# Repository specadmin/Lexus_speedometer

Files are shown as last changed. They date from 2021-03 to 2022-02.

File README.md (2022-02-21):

# Модуль перевода показаний спидометра Lexus RX300 в километры в час #

Владельцы Lexus RX300 американского производства знают, что спидометр данного авто имеет две шкалы - крупную в милях в час и мелкую - в км/ч. В связи с этим считывание показаний спидометра в нужных нам единицах несколько затруднено. Предлагаемое устройство призвано решить эту проблему путем "переноса" действительных показаний спидометра в км/ч с мелкой шкалы на крупную.

Устройство подходит для приборных панелей Lexus RX300 1-го поколения (1998...2003).

Результат выглядит так:
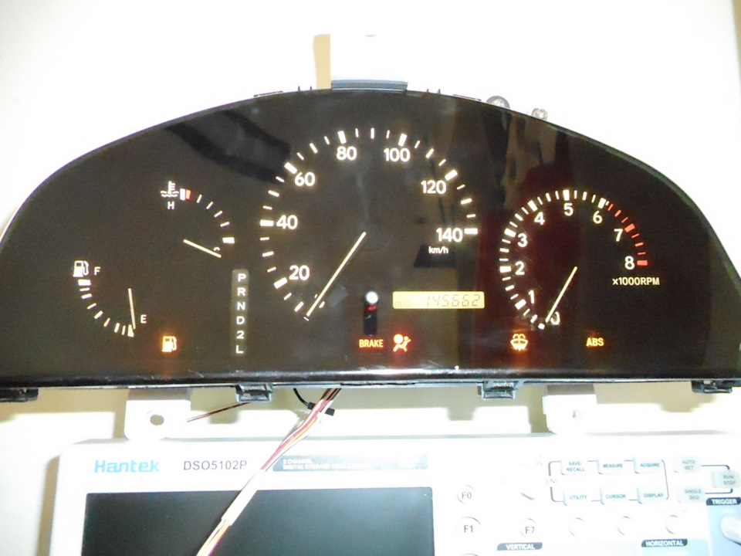
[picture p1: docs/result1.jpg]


Элементы мелкой шкалы и MPH заклеиваются черной изолентой:
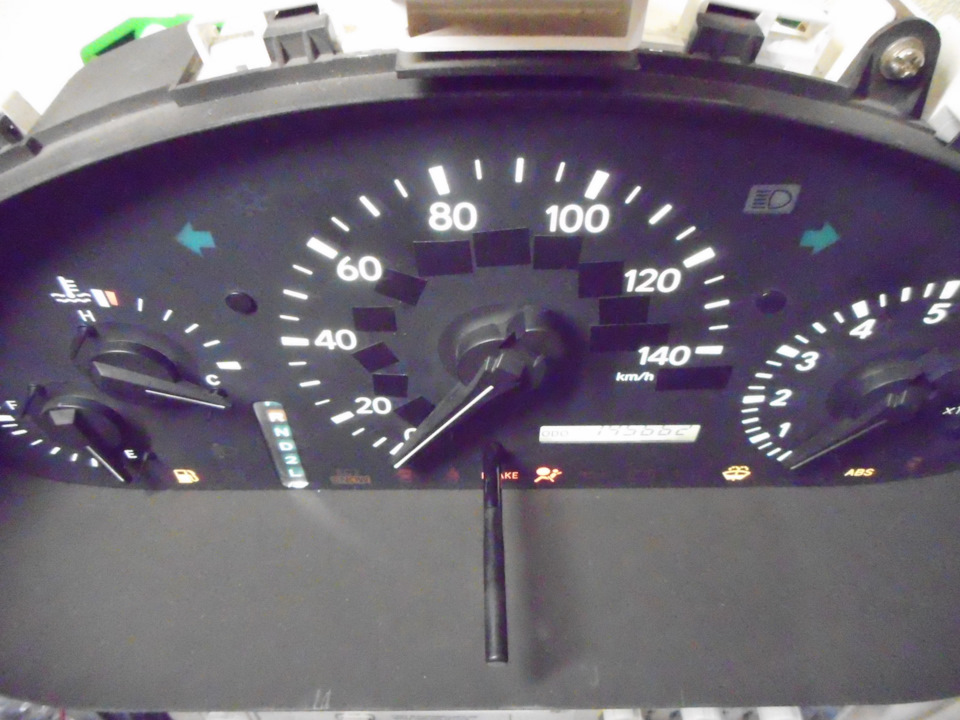
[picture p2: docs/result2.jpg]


Принципиальная схема устройства:
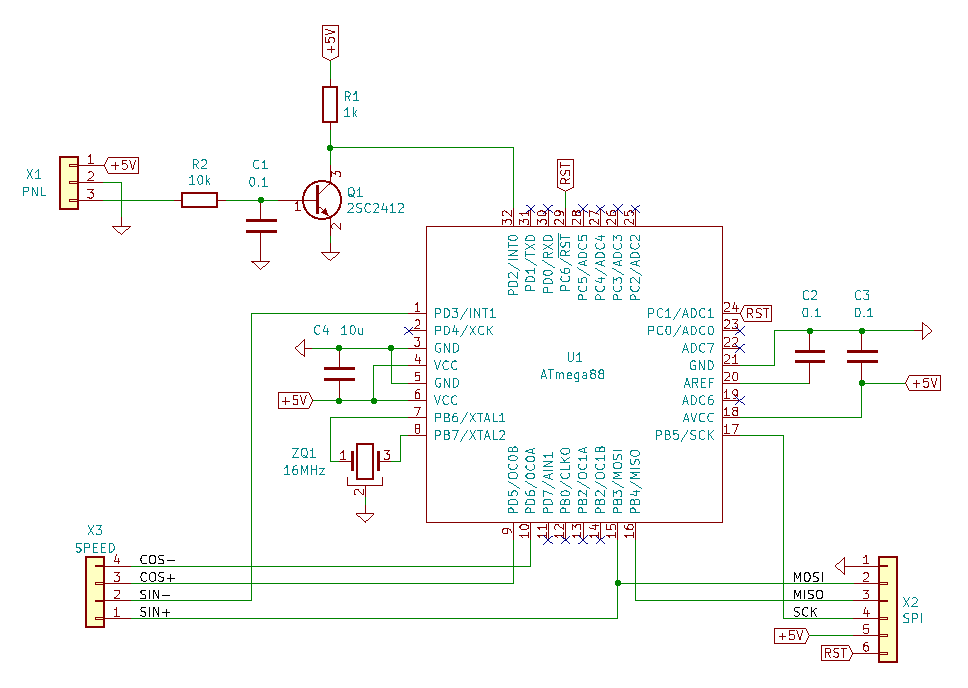
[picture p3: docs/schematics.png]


Больше информации и инструкция по установке здесь: https://www.drive2.ru/l/583354966161298745/

## Готовый модуль ##

Для желающих получить результат быстрее в продаже есть готовые модули:
https://baza.drom.ru/krasnodar/sell_spare_parts/nabor-dlja-perevoda-pokazanij-spidometra-lexus-rx300-v-kilometry-v-chas-99117473.html

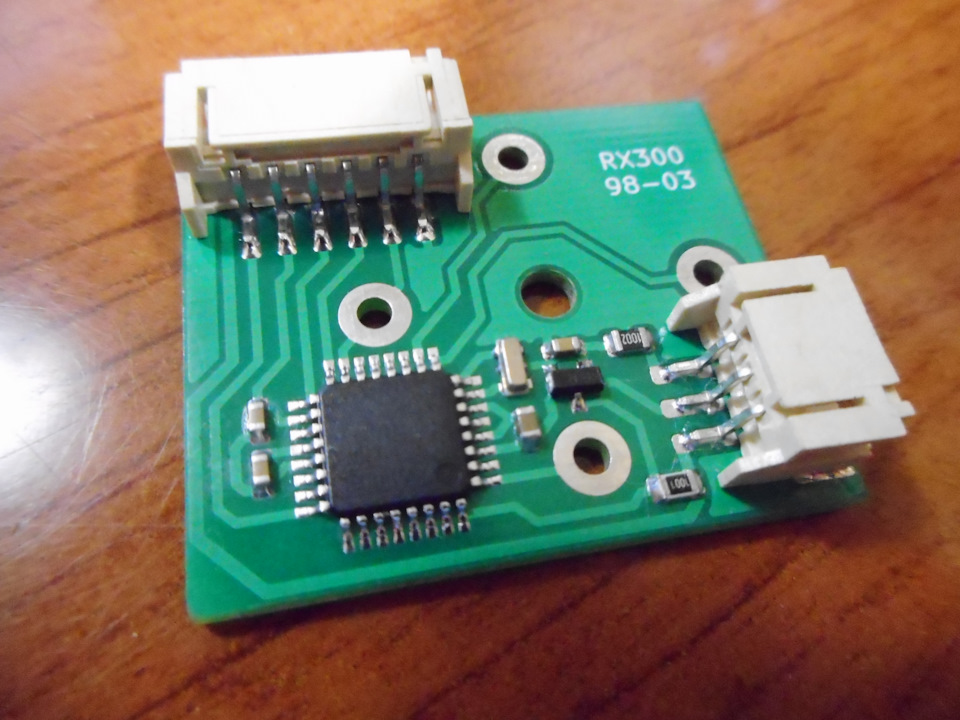
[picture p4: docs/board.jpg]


## Готовая печатная плата ##

Также в продаже имеются печатные платы модуля: https://baza.drom.ru/krasnodar/sell_spare_parts/pechatnaja-plata-dlja-modulja-spidometra-lexus-rx300-99118293.html

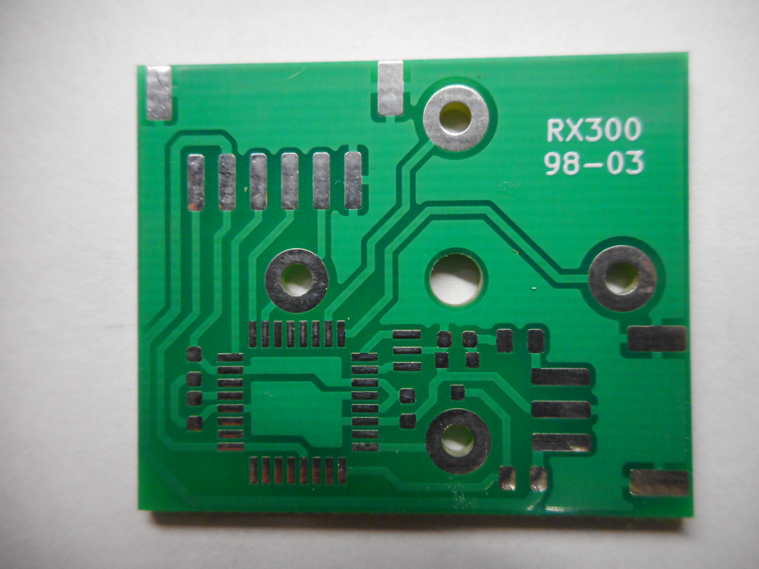
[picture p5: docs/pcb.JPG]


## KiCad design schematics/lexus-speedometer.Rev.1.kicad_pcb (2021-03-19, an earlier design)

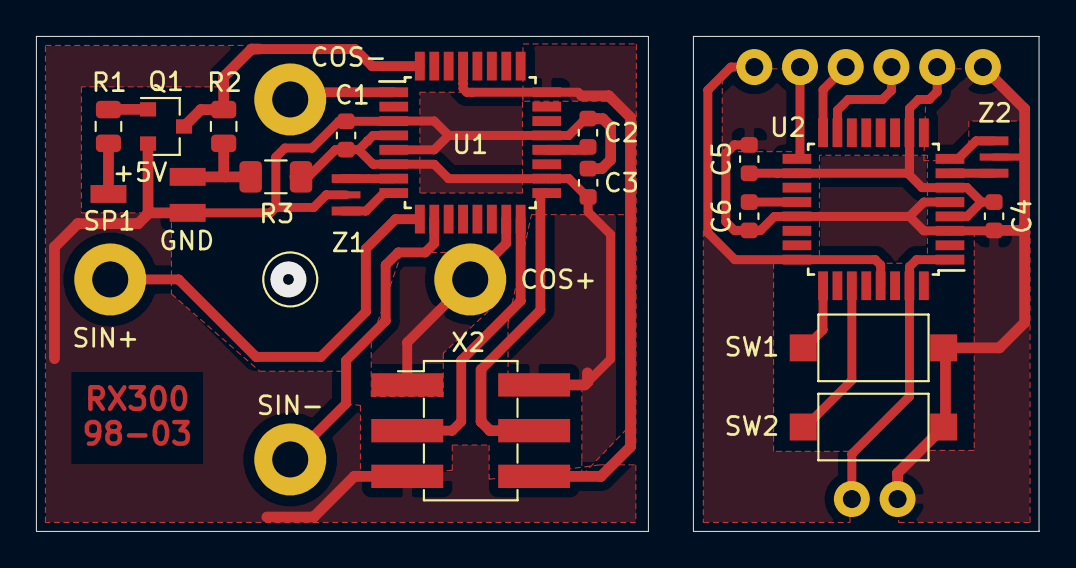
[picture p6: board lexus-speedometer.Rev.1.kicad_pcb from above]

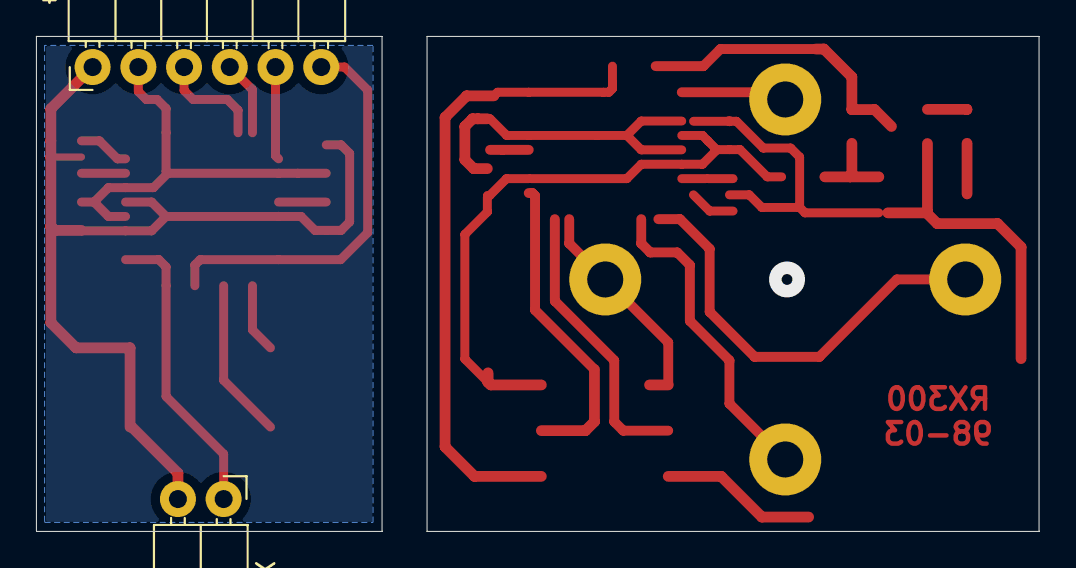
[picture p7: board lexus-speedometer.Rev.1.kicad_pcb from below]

Board: 2 copper layers, 55.7 x 27.5 mm, 23 parts (2 on the bottom side), 25 nets.

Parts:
+5V: Conn_01x01; Soldering_Pad_2.00mm_1.00mm
C1, C4: 10u; C_0603_1608Metric
C2, C3, C5, C6: 0.1; C_0603_1608Metric
GND: Conn_01x01; Soldering_Pad_2.00mm_1.00mm
Q1: 2SC2412; SOT-23
R1: 10k; R_0805_2012Metric
R2: 1k; R_0805_2012Metric
R3: 0; R_1206_3216Metric
SP1: Conn_01x01; Soldering_Pad_2.00mm_1.00mm
SW1: MORE; SW_SPST_CK_RS282G05A3
SW2: LESS; SW_SPST_CK_RS282G05A3
U1, U2: ATmega88; TQFP-32_7x7mm_P0.8mm
X1: SPEED; toyota_potentiometer
X2: SPI; PinHeader_2x03_P2.54mm_Vertical_SMD
X3: OUTPUT; PinHeader_1x02_P2.54mm_Horizontal
X4: SPI; PinHeader_1x06_P2.54mm_Horizontal
Z1, Z2: 16 MHz; Murata_CSTCExxxxV_3213_crystal

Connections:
+5V: C1.1, C3.1, C4.1, C5.1, R3.1, U1.4, U1.6, U1.18, U2.4, U2.6, U2.10, U2.18, X2.4, X4.2
/COS+: U1.15, X1.3, X2.1
/COS-: U1.1, X1.4
/SIN+: U1.9, X1.1
/SIN-: U1.10, X1.2
/VCC: +5V.1, R2.1, R3.2
GND: C1.2, C2.2, C3.2, C4.2, C5.2, C6.2, GND.1, Q1.2, SW1.1, SW2.1, U1.3, U1.5, U1.21, U2.3, U2.5, U2.21, X2.3, X3.2, X4.1, Z1.3, Z2.3
unnamed: C2.1, U1.20
unnamed: C6.1, U2.20
unnamed: Q1.1, R1.1
unnamed: Q1.3, R2.2, U1.32
unnamed: R1.2, SP1.1
unnamed: SW1.2, U2.25
unnamed: SW2.2, U2.27
unnamed: U1.7, Z1.1
unnamed: U1.8, Z1.2
unnamed: U1.16, X2.2
unnamed: U1.17, X2.5
unnamed: U2.1, U2.31, X3.1
unnamed: U2.7, Z2.1
unnamed: U2.8, Z2.2
unnamed: U2.15, X4.3
unnamed: U2.16, X4.4
unnamed: U2.17, X4.5
RST: U1.24, U1.29, U2.24, U2.29, X2.6, X4.6

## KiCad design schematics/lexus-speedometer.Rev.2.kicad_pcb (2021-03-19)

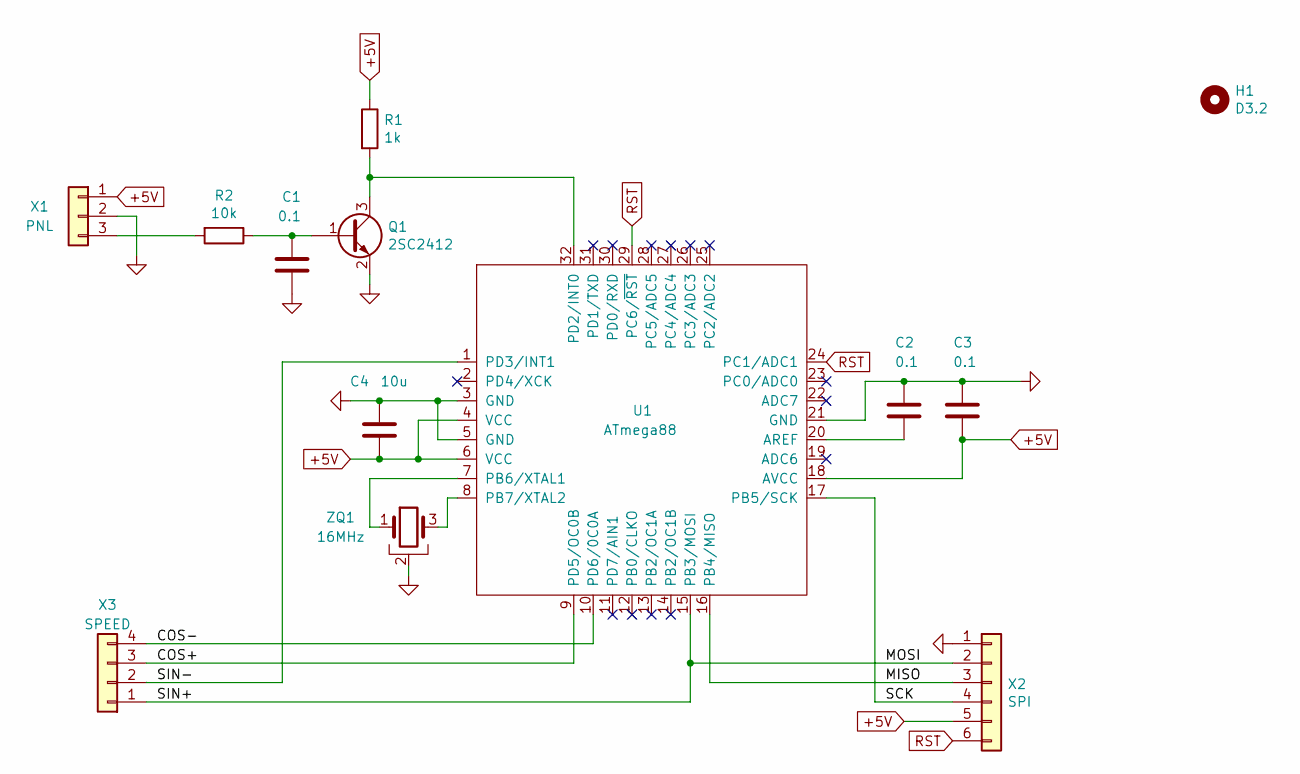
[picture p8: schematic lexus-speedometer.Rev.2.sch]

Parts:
C1, C2, C3: 0.1; C_0603_1608Metric
C4: 10u; C_0603_1608Metric
H1: D3.2; MountingHole_3.2mm_M3
Q1: 2SC2412; SOT-23
R1: 1k; R_0805_2012Metric
R2: 10k; R_0805_2012Metric
U1: ATmega88; TQFP-32_7x7mm_P0.8mm
X1: PNL; JST_PH_S3B-PH-SM4-TB_1x03-1MP_P2.00mm_Horizontal
X2: SPI; JST_PH_S6B-PH-SM4-TB_1x06-1MP_P2.00mm_Horizontal
X3: SPEED; toyota_potentiometer
ZQ1: 16MHz; Resonator_SMD_Murata_CSTxExxV-3Pin_3.2x1.3mm

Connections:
+5V: C3.1, C4.1, R1.1, U1.4 (VCC), U1.6 (VCC), U1.18 (AVCC), X1.1, X2.5
/COS+: U1.9 (PD5/OC0B), X3.3
/COS-: U1.10 (PD6/0C0A), X3.4
/MISO: U1.16 (PB4/MISO), X2.3
/MOSI: U1.15 (PB3/MOSI), X2.2, X3.1
/SCK: U1.17 (PB5/SCK), X2.4
/SIN-: U1.1 (PD3/INT1), X3.2
GND: C1.1, C2.2, C3.2, C4.2, Q1.2 (E), U1.3 (GND), U1.5 (GND), U1.21 (GND), X1.2, X1.MP, X2.1, X2.MP, ZQ1.2
unnamed: C1.2, Q1.1 (B), R2.1
unnamed: C2.1, U1.20 (AREF)
unnamed: Q1.3 (C), R1.2, U1.32 (PD2/INT0)
unnamed: R2.2, X1.3
unnamed: U1.7 (PB6/XTAL1), ZQ1.1
unnamed: U1.8 (PB7/XTAL2), ZQ1.3
RST: U1.24 (PC1/ADC1), U1.29 (PC6/~RST), X2.6

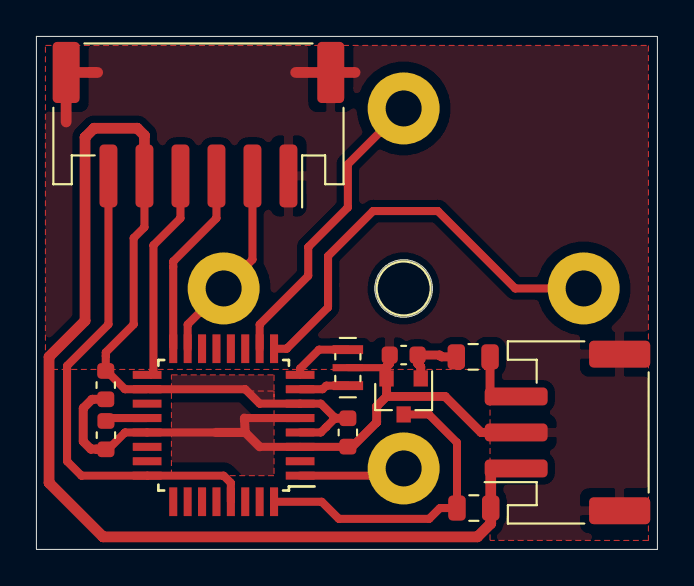
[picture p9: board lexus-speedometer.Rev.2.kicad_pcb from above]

Board: 2 copper layers, 34.5 x 28.5 mm, 13 parts (0 on the bottom side), 15 nets.

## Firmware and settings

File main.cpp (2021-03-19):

//-----------------------------------------------------------------------------
#include <avr/io.h>
#include <avr/sleep.h>
#include "lib/avr-misc/avr-misc.h"
#include "lib/avr-debug/debug.h"
#include "potentiometer.h"
#include "config.h"
//-----------------------------------------------------------------------------
static BYTE scale_180 = 0;
//-----------------------------------------------------------------------------
#define K_180               9639    // = sec_in_hour * k * (1 + disp) = 3600 * 2.625 * (1 + 2%)
#define K_140               12639   // = sec_in_hour * k * (1 + disp) = 3600 * 3.442 * (1 + 2%)
#define B                   58
#define CLK_IN_KM           2560
//-----------------------------------------------------------------------------
__inline void init()
{
    set_position(180); mdelay(200);

    //set_position(90); mdelay(200);
    //halt();
    set_position(360); mdelay(200);
    set_position(450); mdelay(300);
    set_position(540); mdelay(800);
    set_position(270); mdelay(400);
    set_position(180); mdelay(200);
    set_position(B);   mdelay(500);
}
//-----------------------------------------------------------------------------
__inline void enable_input()
{
    set_bit(EIMSK, INT0);
}
//-----------------------------------------------------------------------------
__inline void disable_input()
{
    clr_bit(EIMSK, INT0);
}
//-----------------------------------------------------------------------------
__inline void enable_outputs()
{
    set_bits(DDRD, 3, 5, 6);
    set_bits(DDRB, 3);
}
//-----------------------------------------------------------------------------
__inline void disable_outputs()
{
    clr_bits(DDRD, 3, 5, 6);
    clr_bits(DDRB, 3);
}
//-----------------------------------------------------------------------------
__inline void start_timer()
{
    TCNT1 = 0;
    TCCR1B = 0x03;      // 64 prescaler for input clock
}
//-----------------------------------------------------------------------------
__inline void stop_timer()
{
    TCCR1B = 0;
}
//-----------------------------------------------------------------------------
void sleep()
{
    disable_interrupts();
    set_sleep_mode(SLEEP_MODE_PWR_DOWN);
    sleep_enable();
    sleep_bod_disable();
    enable_interrupts();
    sleep_cpu();
    sleep_disable();
}
//-----------------------------------------------------------------------------
int main()
{
    // divide crystal frequency by 4
    CLKPR = 0x80;
    CLKPR = 0x02;

    DEBUG_INIT();

    enable_outputs();

    // fast-PWM mode for output
    TCCR0A = 0x03;
    TCCR2A = 0x03;

    // start output timers
    TCCR0B = 1;
    TCCR2B = 1;

    init();

    // falling edge interrupt input
    EICRA = 0x02;

    set_bit(TIMSK1, TOIE1);
    start_timer();
    enable_interrupts();

    while(1);
    return 0;
}
//-----------------------------------------------------------------------------
ISR(TIMER1_OVF_vect)
{
    // set zero position
    set_position(B); mdelay(200);

    // enable pin-change interrupt (for waking-up)
    PCMSK2 = 0x04;
    PCICR = 0x04;

    disable_outputs();
    disable_input();

    // enter power down mode
    sleep();
}
//-----------------------------------------------------------------------------
ISR(PCINT2_vect)
{
    // disable pin-change interrupt
    PCMSK2 = 0;
    // clear pending interrupt flag
    EIFR = 1;
    enable_input();
}
//-----------------------------------------------------------------------------
ISR(INT0_vect)
{
    WORD value;
    WORD clocks = TCNT1;
    TCNT1 = 0;

    enable_outputs();

    // filter LSB
    clocks >>= 1;
    clocks <<= 1;

    if(scale_180)
    {
        // 180 km/h scale
        value = F_CPU / 64 * K_180 / CLK_IN_KM / clocks + B;
    }
    else
    {
        // 140 km/h scale
        value = F_CPU / 64 * K_140 / CLK_IN_KM / clocks + B;
    }

    set_position(value);
}
//-----------------------------------------------------------------------------
